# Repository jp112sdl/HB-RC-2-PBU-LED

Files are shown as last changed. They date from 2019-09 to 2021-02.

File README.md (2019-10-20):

# HB-RC-2-PBU-LED

**2 fach Wandtaster, ähnlich dem [HmIP-BSL](https://www.elv.de/elv-homematic-ip-schaltaktor-fuer-markenschalter-mit-signalleuchte-hmip-bsl.html), mit RGB LED Beleuchtung (oben/unten)).**

Thread im Homematic Forum: https://homematic-forum.de/forum/viewtopic.php?f=76&t=53254

### Bauteile
| Anzahl | Ref | Typ | Bezeichnung |
|----|----|----|----|
1 | U1 | AVR | [ATMega 328P-AU](https://www.reichelt.de/mcu-atmega-avr-risc-32-kb-20-mhz-tqfp-32-atmega-328p-au-p119684.html)
2 | R1, R2 | Widerstand 330 | [RND 0805 330](https://www.reichelt.de/smd-widerstand-0805-330-ohm-125-mw-1-rnd-0805-1-330-p183184.html)
2 | R3, R4 | Widerstand 10k | [RND 0805 10k](https://www.reichelt.de/smd-widerstand-0805-10-kohm-125-mw-1-rnd-0805-1-10k-p183251.html)
4 | C2, C4, C5, C7 |Kondensator 100n |[X7R-G0805 100N](https://www.reichelt.de/smd-vielschicht-keramikkondensator-100n-10-x7r-g0805-100n-p31879.html)
1 | C1 | ELKO 1µF/50V | [SMD ELKO 1,0/50](https://www.reichelt.de/smd-chip-elko-1-0-f-50volt-smd-elko-1-0-50-p31900.html)
2 | C3, C6 | ELKO 10µF/16V | [SMD ELKO 10/16](https://www.reichelt.de/smd-chip-elko-10-f-16volt-smd-elko-10-16-p31906.html)
1 | U2 | LDO | [TLV1117-33](https://www.reichelt.de/ldo-regler-fest-3-3-v-sot-223-4-tlv-1117-33-cdcy-p188993.html)
1 | D1 | DuoLED 3mm | [RND 135-00023](https://www.reichelt.de/led-3-mm-bedrahtet-rot-gruen-20-mcd-40-rnd-135-00023-p224130.html)
1 | U3 | LevelShifter | [SN74LVC1T45DBVR](https://www.aliexpress.com/item/32963167201.html)
1 | IC1 | 868MHz Funkmodul | [CC1101](https://www.aliexpress.com/item/32924239954.html)
1 | SW1, SW2, SW3 | Taster | [Tastersortiment](https://www.aliexpress.com/item/32811153729.html)
2 | |WS2812B LED Streifen | [NeoPixel-Stick-WS2812](https://www.amazon.de/NeoPixel-Stick-WS2812-5050-LEDs/dp/B019ZKN3XQ)

### PCB

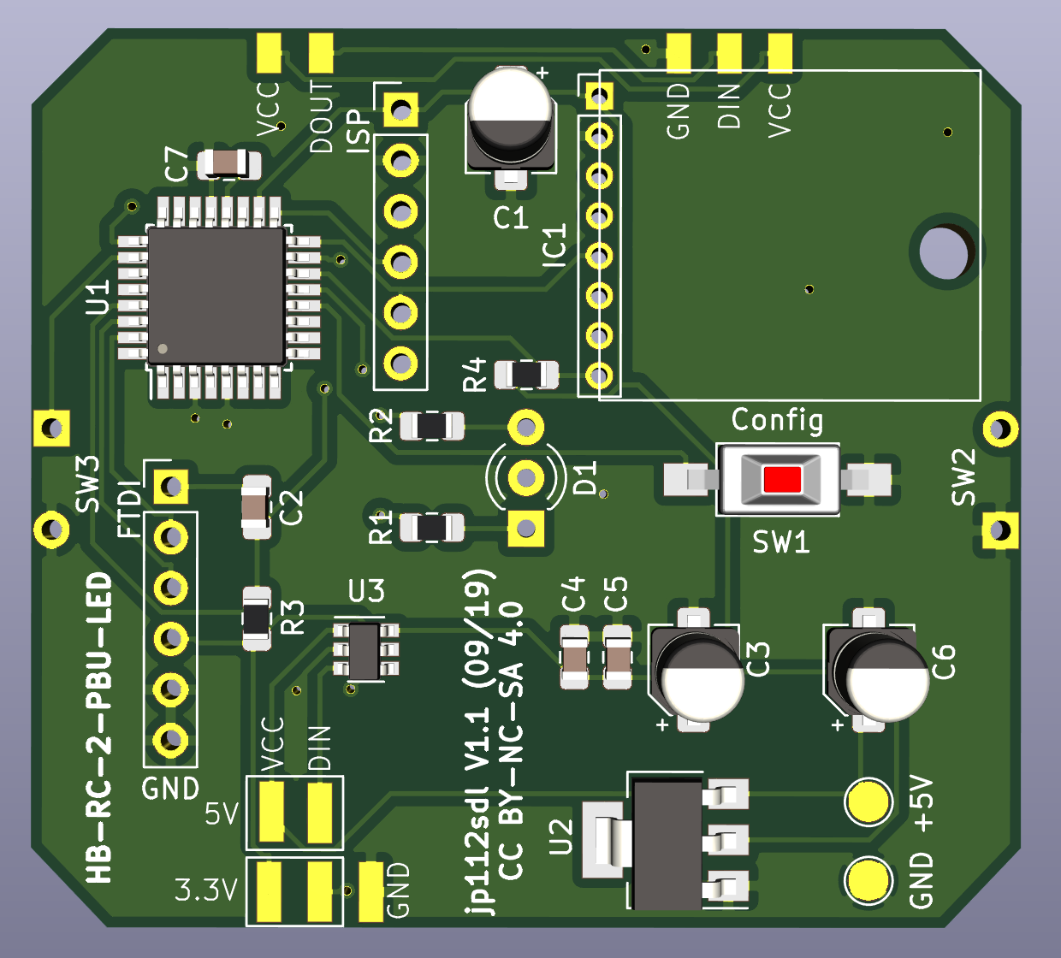
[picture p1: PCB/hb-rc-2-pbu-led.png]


### ein paar Bilder

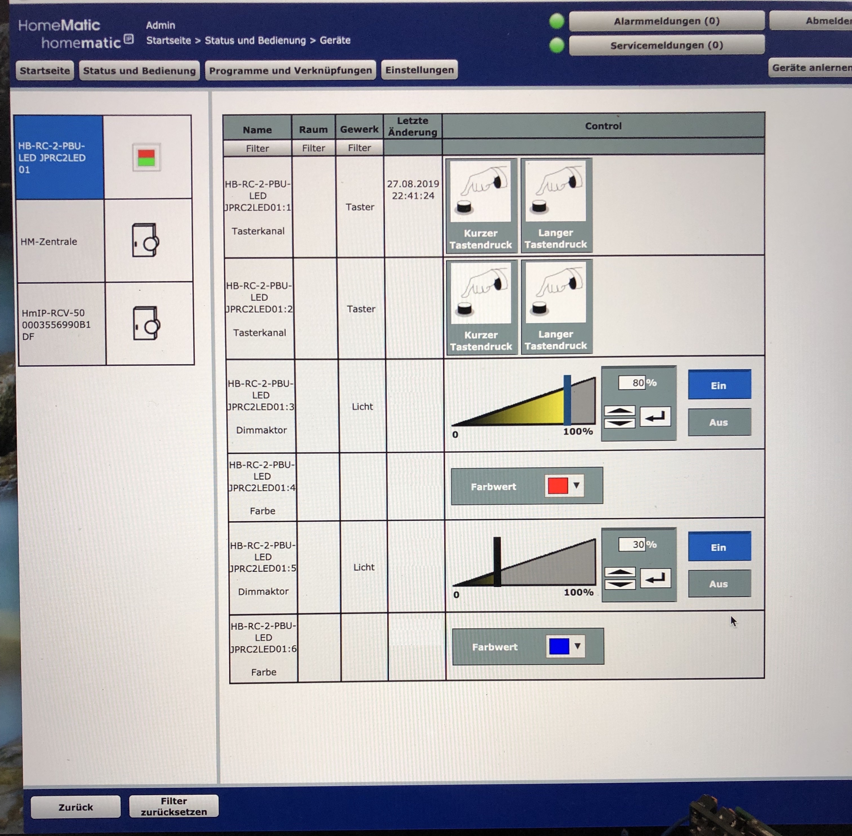
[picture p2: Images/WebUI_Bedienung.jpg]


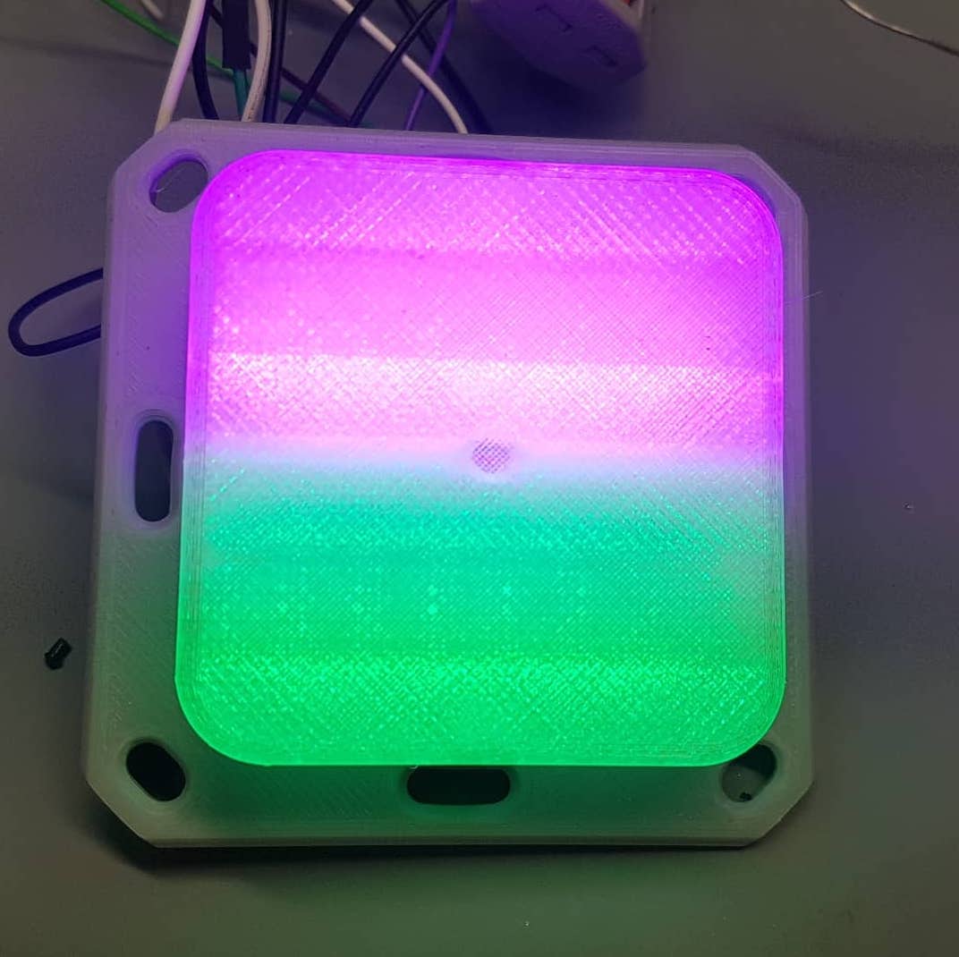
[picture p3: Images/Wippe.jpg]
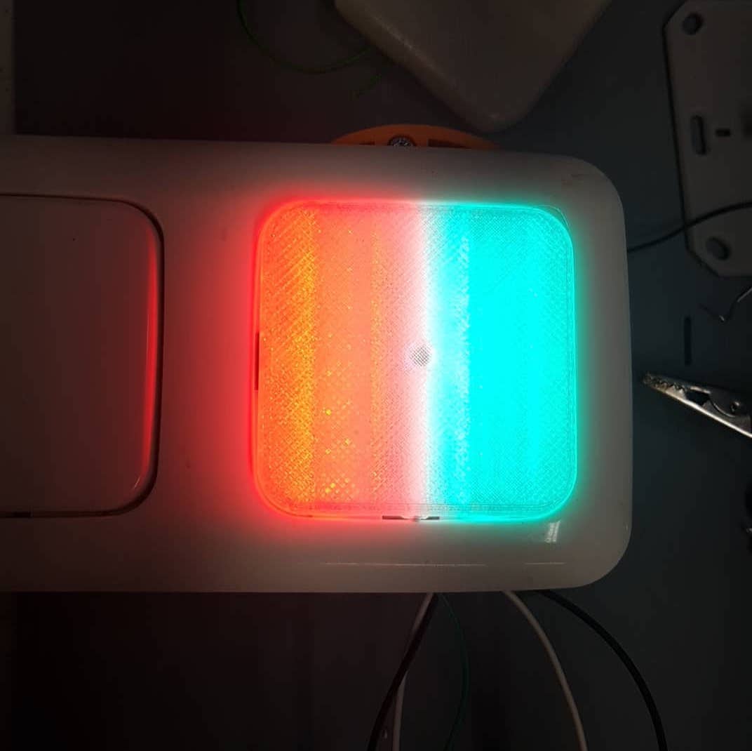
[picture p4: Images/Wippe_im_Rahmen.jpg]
 

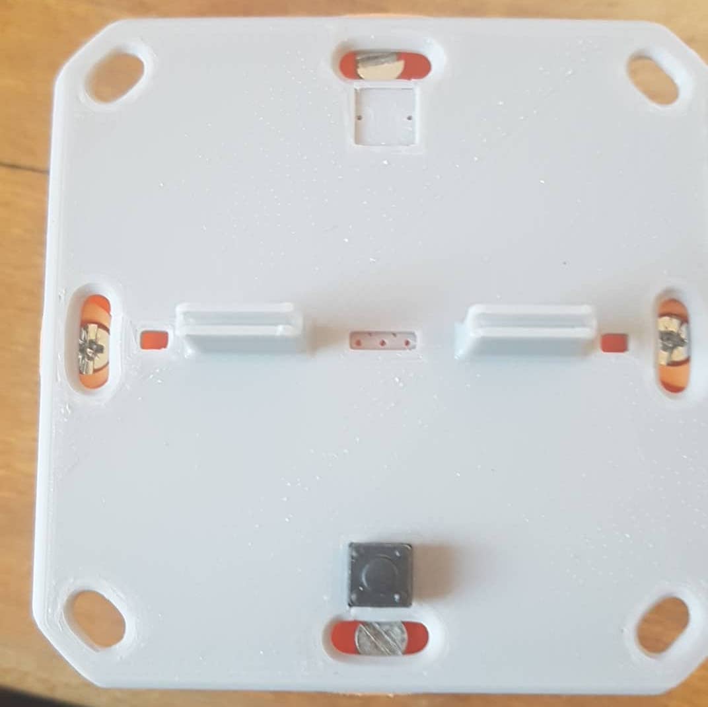
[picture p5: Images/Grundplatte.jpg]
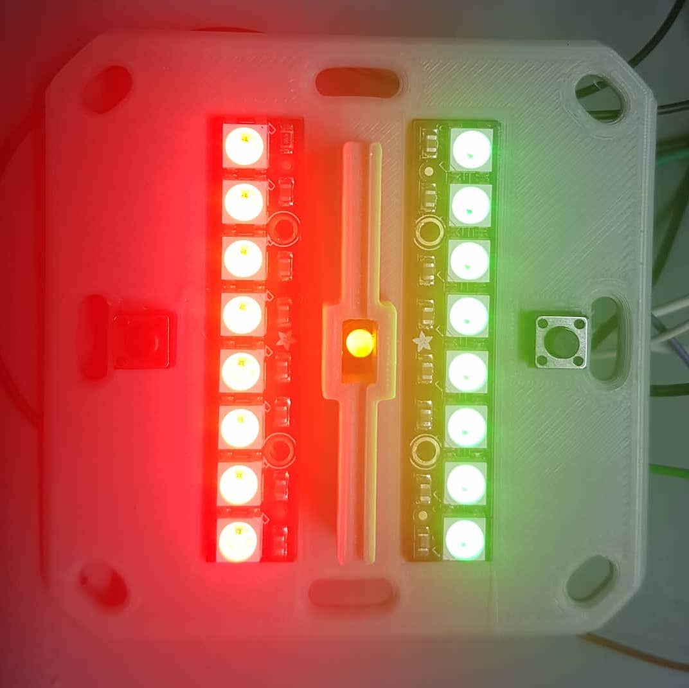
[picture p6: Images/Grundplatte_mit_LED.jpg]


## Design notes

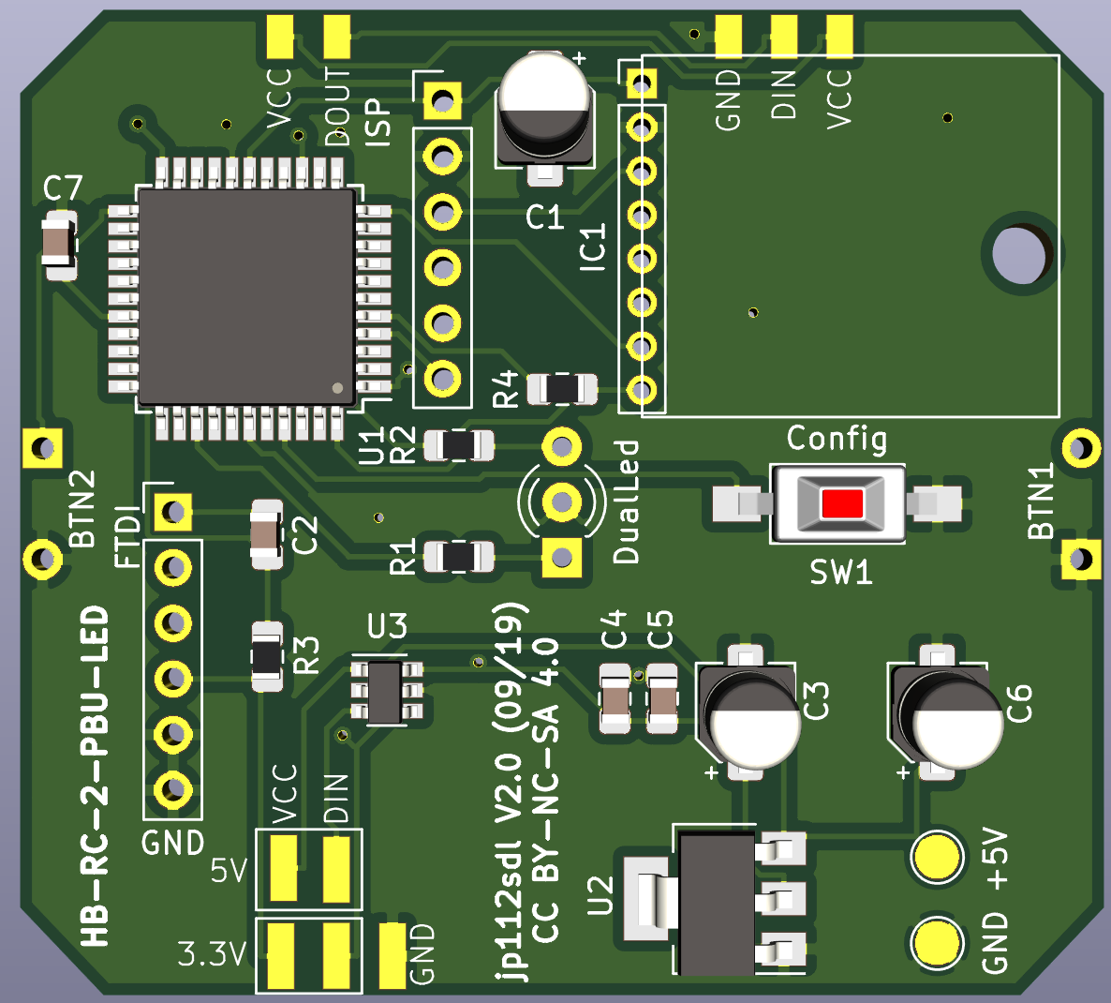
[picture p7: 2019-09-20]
PCB644/hb-rc-2-pbu-led.png

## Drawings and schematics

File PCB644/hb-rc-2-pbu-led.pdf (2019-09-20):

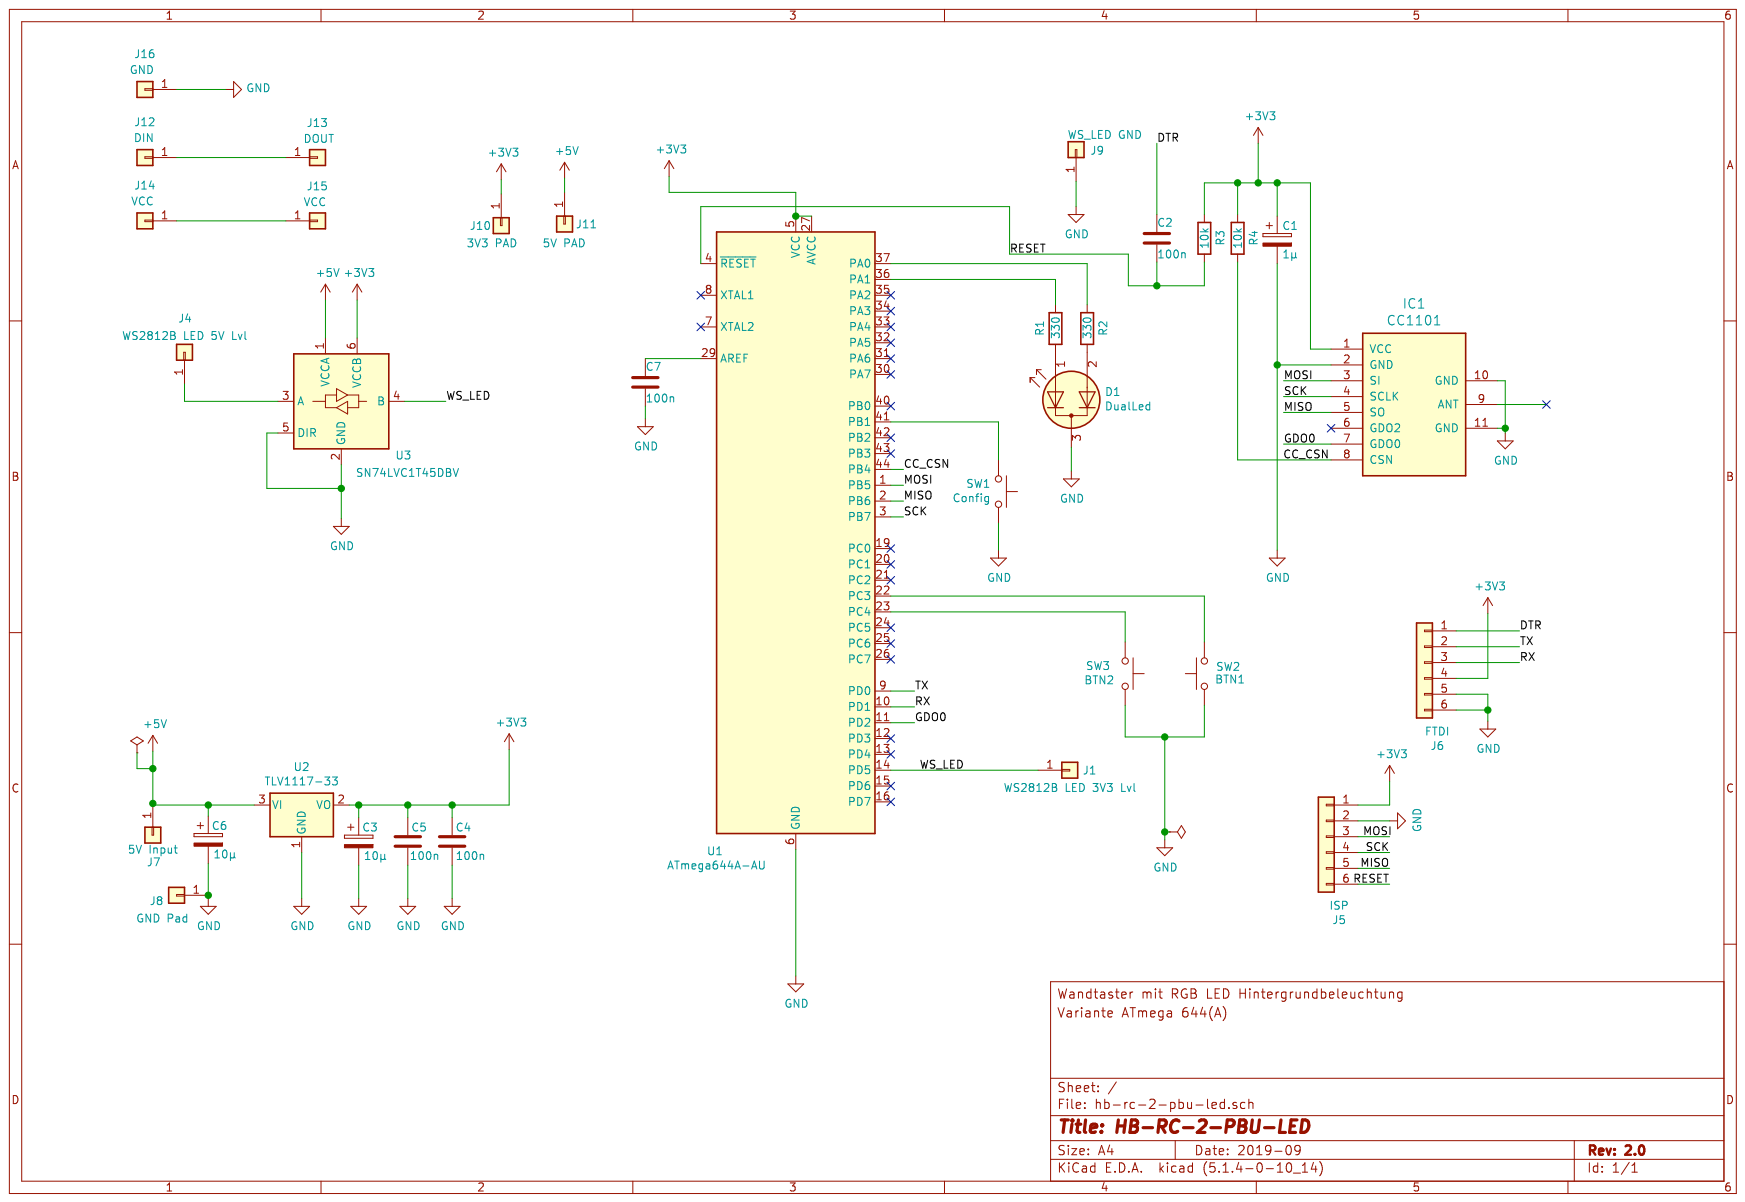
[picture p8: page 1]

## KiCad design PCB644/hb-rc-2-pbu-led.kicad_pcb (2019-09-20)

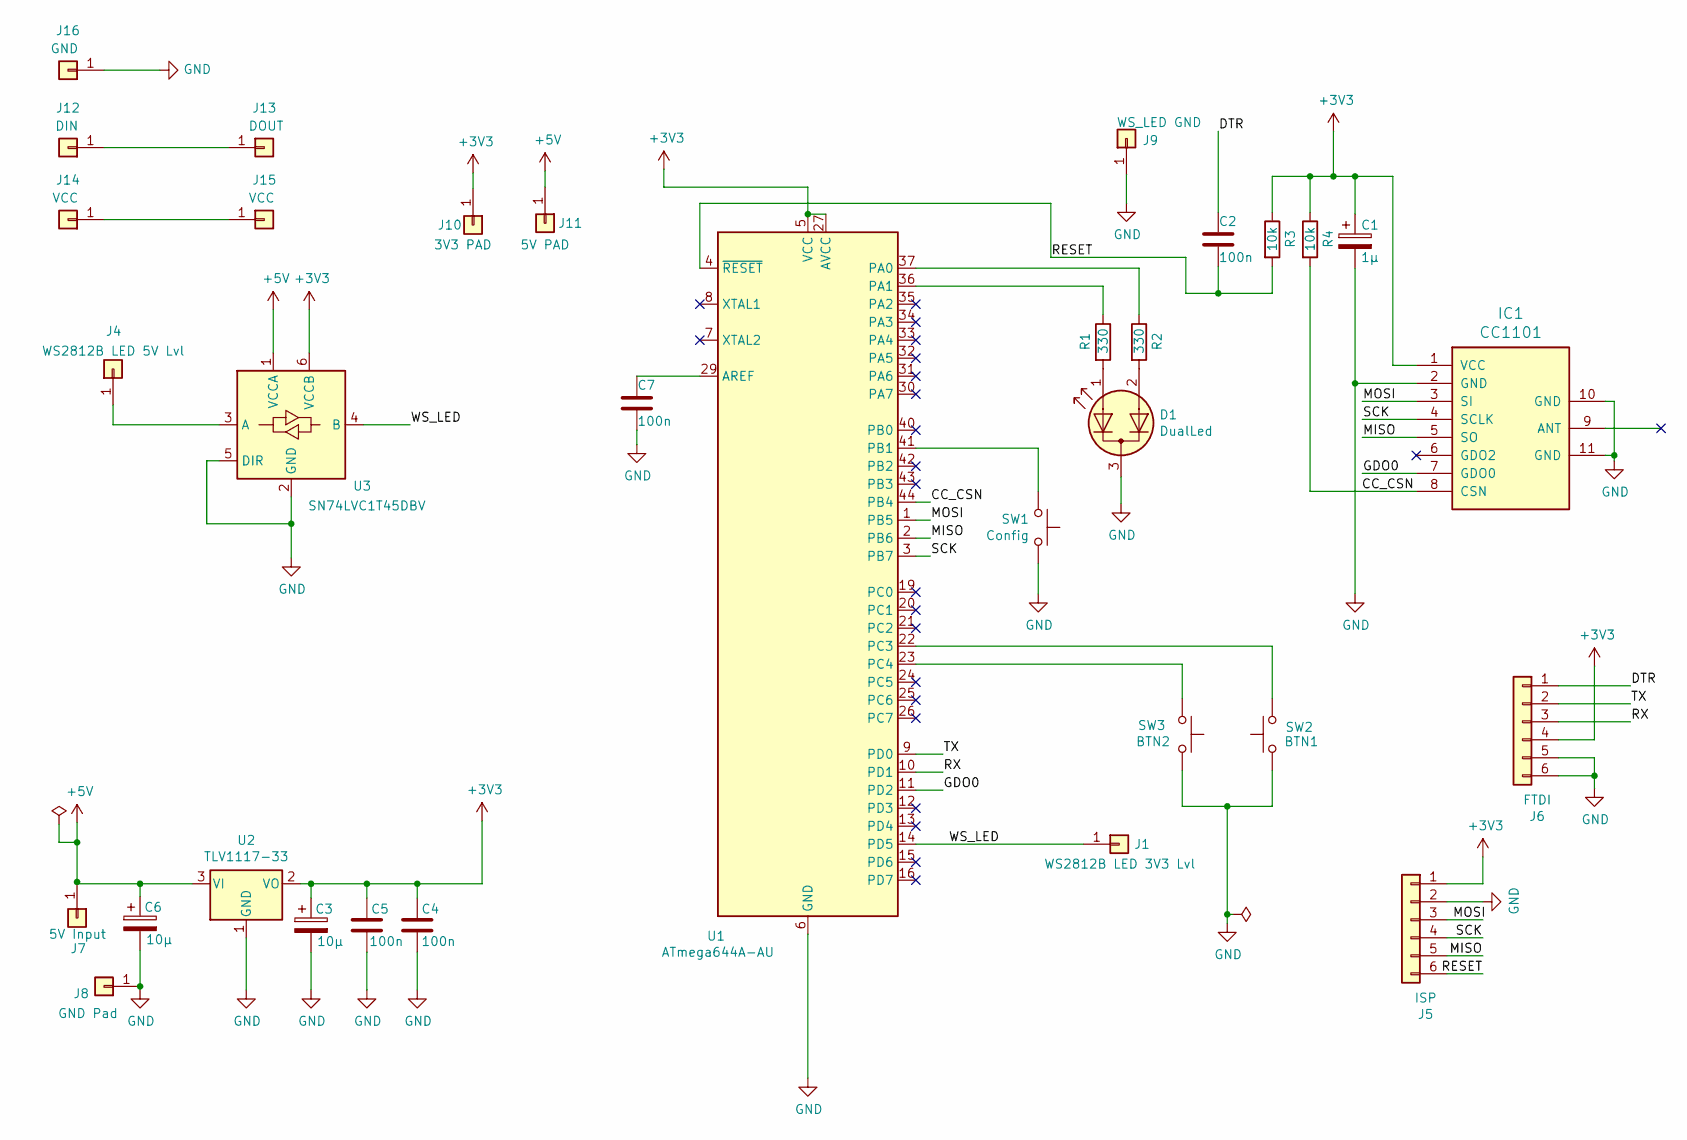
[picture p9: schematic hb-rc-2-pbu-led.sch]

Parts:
C1: 1µ; CP_Elec_4x5.3
C2, C4, C5, C7: 100n; C_0805_2012Metric_Pad1.15x1.40mm_HandSolder
C3, C6: 10µ; CP_Elec_4x5.4
D1: DualLed; LED_D3.0mm-3
IC1: CC1101; PinHeader_1x08_P2.00mm_Vertical
J1: WS2812B LED 3V3 Lvl; TestPoint_Pad_D2.0mm
J4: WS2812B LED 5V Lvl; TestPoint_Pad_D2.0mm
J5: ISP; PinHeader_1x06_P2.54mm_Vertical
J6: FTDI; PinHeader_1x06_P2.54mm_Vertical
J7: 5V Input; TestPoint_Pad_D2.0mm
J8: GND Pad; TestPoint_Pad_D2.0mm
J9: WS_LED GND; TestPoint_Pad_D2.0mm
J10: 3V3 PAD; TestPoint_Pad_D2.0mm
J11: 5V PAD; TestPoint_Pad_D2.0mm
J12: DIN; TestPoint_Pad_D2.0mm
J13: DOUT; TestPoint_Pad_D2.0mm
J14, J15: VCC; TestPoint_Pad_D2.0mm
J16: GND; TestPoint_Pad_D2.0mm
R1, R2: 330; R_0805_2012Metric_Pad1.15x1.40mm_HandSolder
R3, R4: 10k; R_0805_2012Metric_Pad1.15x1.40mm_HandSolder
SW1: Config; SW_SPST_FSMSM
SW2: BTN1; TO-126-2_Vertical
SW3: BTN2; TO-126-2_Vertical
U1: ATmega644A-AU; TQFP-44_10x10mm_P0.8mm
U2: TLV1117-33; SOT-223
U3: SN74LVC1T45DBV; SOT-23-6

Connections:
+3V3: C1.1, C3.1, C4.1, C5.1, IC1.1 (VCC), J5.1, J6.4, J10.1, R3.1, R4.1, U1.5 (VCC), U1.17 (VCC), U1.27 (AVCC), U1.38 (VCC), U2.2 (VO), U3.6 (VCCB)
+5V: C6.1, J7.1, J11.1, U2.3 (VI), U3.1 (VCCA)
/CC_CSN: IC1.8 (CSN), R4.2, U1.44 (PB4)
/DTR: C2.1, J6.1
/GDO0: IC1.7 (GDO0), U1.11 (PD2)
/MISO: IC1.5 (SO), J5.5, U1.2 (PB6)
/MOSI: IC1.3 (SI), J5.3, U1.1 (PB5)
/RESET: C2.2, J5.6, R3.2, U1.4 (~RESET)
/RX: J6.3, U1.10 (PD1)
/SCK: IC1.4 (SCLK), J5.4, U1.3 (PB7)
/TX: J6.2, U1.9 (PD0)
/WS_LED: J1.1, U1.14 (PD5), U3.4 (B)
GND: C1.2, C3.2, C4.2, C5.2, C6.2, C7.2, D1.3 (K), IC1.2 (GND), IC1.10 (GND), IC1.11 (GND), J5.2, J6.5, J6.6, J8.1, J9.1, J16.1, SW1.1, SW2.1, SW3.2, U1.6 (GND), U1.18 (GND), U1.28 (GND), U1.39 (GND), U2.1 (GND), U3.2 (GND), U3.5 (DIR)
unnamed: C7.1, U1.29 (AREF)
unnamed: D1.1 (A1), R1.2
unnamed: D1.2 (A2), R2.2
unnamed: J4.1, U3.3 (A)
unnamed: J12.1, J13.1
unnamed: J14.1, J15.1
unnamed: R1.1, U1.36 (PA1)
unnamed: R2.1, U1.37 (PA0)
unnamed: SW1.2, U1.41 (PB1)
unnamed: SW2.2, U1.22 (PC3)
unnamed: SW3.1, U1.23 (PC4)

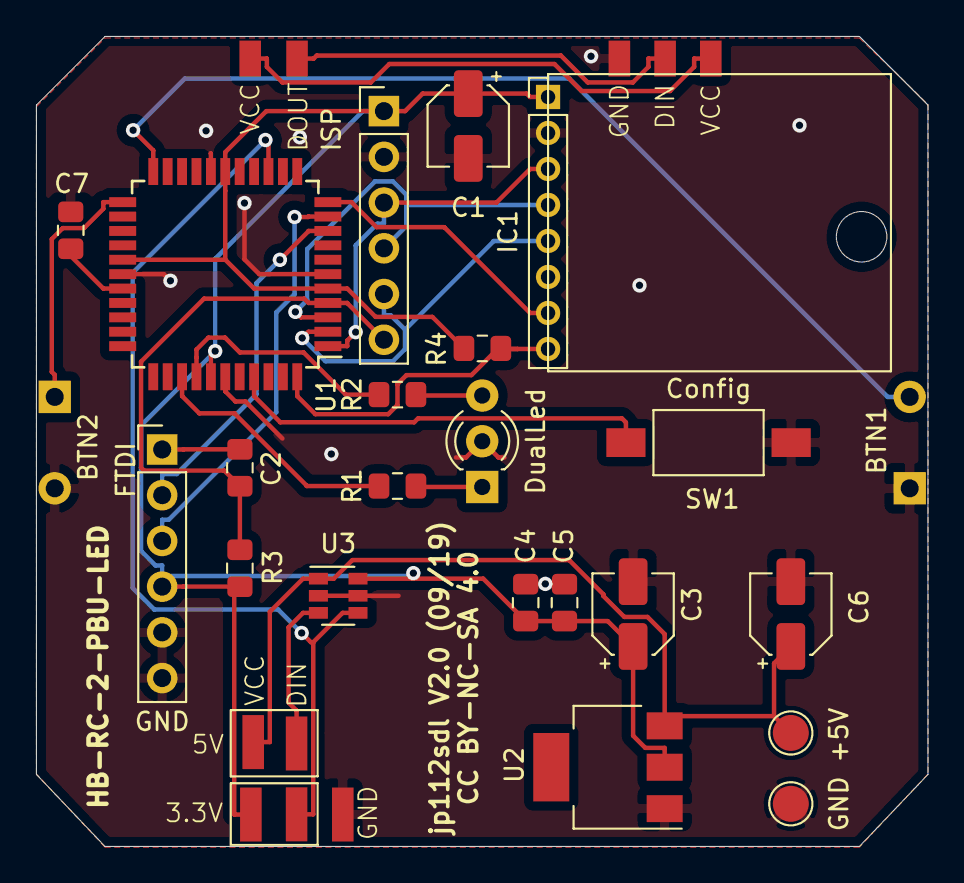
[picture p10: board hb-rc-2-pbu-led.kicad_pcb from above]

Board: 2 copper layers, 49.5 x 45.0 mm, 33 parts (0 on the bottom side), 24 nets.

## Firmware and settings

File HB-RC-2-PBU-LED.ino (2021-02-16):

//- -----------------------------------------------------------------------------------------------------------------------
// AskSin++
// 2019-08-26 jp112sdl Creative Commons - http://creativecommons.org/licenses/by-nc-sa/3.0/de/
//- -----------------------------------------------------------------------------------------------------------------------
// ci-test=yes board=328p aes=no

// define this to read the device id, serial and device type from bootloader section
// #define USE_OTA_BOOTLOADER

#define EI_NOTEXTERNAL
#include <EnableInterrupt.h>
#include <SPI.h>
#include <AskSinPP.h>
#include <LowPower.h>
#include <Register.h>
#include <MultiChannelDevice.h>
#include <FastLED.h>
#include <Remote.h>
#include <Dimmer.h>

//Pin Definitionen (when using 644P(A): use Standard Pinout)

#ifdef __AVR_ATmega328P__
#define CONFIG_BUTTON_PIN 8
#define WSLED_PIN         9      //GPIO Pin LED Anschluss
#define ONBOARD_LED_PIN1  14
#define ONBOARD_LED_PIN2  15
#define CC1101_CS         10
#define CC1101_GDO0       2
#define BTN1_PIN          16
#define BTN2_PIN          17
#endif

#ifdef __AVR_ATmega644P__
#define CONFIG_BUTTON_PIN 1       //PB1
#define WSLED_PIN         13      //PD5 GPIO Pin LED Anschluss
#define ONBOARD_LED_PIN1  25      //PA1
#define ONBOARD_LED_PIN2  24      //PA0
#define CC1101_CS         4       //PB4
#define CC1101_GDO0       10      //PD2
#define BTN1_PIN          19      //PC3
#define BTN2_PIN          20      //PC4
#endif


//Einstellungen für die RGB LEDs
#define WSNUM_LEDS    16          //Anzahl angeschlossener LEDs
#define WSLED_TYPE    WS2812B    //LED Typ
#define WSCOLOR_ORDER GRB        //Farbreihenfolge

uint8_t dim1level(0);
uint8_t dim2level(0);
uint8_t col1val(0);
uint8_t col2val(0);
CRGB leds[WSNUM_LEDS];


#define PEERS_PER_RGB_CHANNEL  3
#define PEERS_PER_RC_CHANNEL   12

using namespace as;

const struct DeviceInfo PROGMEM devinfo = {
  {0xF3, 0x30, 0x00},     // Device ID
  "JPRC2LED01",           // Device Serial
  {0xF3, 0x30},           // Device Model
  0x10,                   // Firmware Version
  as::DeviceType::Dimmer, // Device Type
  {0x01, 0x00}            // Info Bytes
};

typedef AskSin<DualStatusLed<ONBOARD_LED_PIN1, ONBOARD_LED_PIN2>, NoBattery, Radio<LibSPI<CC1101_CS>, CC1101_GDO0>> Hal;
Hal hal;

typedef RemoteChannel<Hal, PEERS_PER_RC_CHANNEL, DimmerList0> RemoteChannelType;
typedef DimmerChannel<Hal, PEERS_PER_RGB_CHANNEL,DimmerList0> RGBLEDChannelType;
typedef DimmerAndRemoteDevice<Hal, RGBLEDChannelType, RemoteChannelType, 4, 1, 2, DimmerList0> RCLEDDevice;

// we need no PWM class
class DummyPWM {
public:
  void init(uint8_t __attribute__ ((unused)) pwm) {}
  void set(uint8_t __attribute__ ((unused)) pwm) {}
  void param(uint8_t __attribute__ ((unused)) speedMultiplier, uint8_t __attribute__ ((unused)) characteristic) {}
};

template<class HalType,class DimmerType,class PWM>
class RGBControl : public DimmerControl<HalType,DimmerType,PWM> {
public:
  typedef DimmerControl<HalType,DimmerType,PWM> BaseControl;
  RGBControl (DimmerType& dim) : BaseControl(dim) {
    for (int i = 0; i < WSNUM_LEDS; i++) {
      leds[i] = CRGB::Black;
    }
    FastLED.addLeds<WSLED_TYPE, WSLED_PIN, WSCOLOR_ORDER>(leds, WSNUM_LEDS);
    FastLED.setBrightness(255);
  }

  virtual ~RGBControl () {}

  virtual void updatePhysical () {
    // first calculate all physical values of the dimmer channels
    BaseControl::updatePhysical();
    // set brightness and color to LEDs
    uint8_t ledprocombi = WSNUM_LEDS / (this->physicalCount() / 2);
    uint8_t ledidx = 0;
    for( uint8_t i=0; i<this->physicalCount();  ) {
      uint8_t dimlevel = this->physical[i++];
      uint8_t collevel = this->physical[i++];
      CRGB ledvalue = CHSV((collevel * 1275L) / 1000, (collevel <  200) ? 255 : 0, dimlevel);
      // set to real LEDs
      for( uint8_t y=0; y<ledprocombi; ++y) {
        leds[ledidx++] = ledvalue;
      }
    }
    FastLED.show();
  }
};

RCLEDDevice sdev(devinfo, 0x20);
RGBControl<Hal,RCLEDDevice,DummyPWM> control(sdev);
ConfigButton<RCLEDDevice> cfgBtn(sdev);

void setup () {
  DINIT(57600, ASKSIN_PLUS_PLUS_IDENTIFIER);
  uint8_t pins[4] = {0,0,0,0}; // all 4 PWM pins are 0
  control.init(hal,pins);
  remoteChannelISR(sdev.remoteChannel(1), BTN1_PIN);
  remoteChannelISR(sdev.remoteChannel(2), BTN2_PIN);
  buttonISR(cfgBtn, CONFIG_BUTTON_PIN);
  sdev.initDone();
}

void loop() {
  bool worked = hal.runready();
  bool poll = sdev.pollRadio();
  if ( worked == false && poll == false ) {
    hal.activity.savePower<Idle<true>>(hal);
  }
}

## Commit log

2019-09-01 use 16 ws2812b leds
2019-09-10 add gerber
    [hb-rc-2-pbu-led-B_Cu.gbr, hb-rc-2-pbu-led-B_Mask.gbr, hb-rc-2-pbu-led-B_SilkS.gbr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]
2019-09-10 add pcb
    [hb-rc-2-pbu-led.kicad_pcb, hb-rc-2-pbu-led.sch]
2019-09-10 pcb update
    [hb-rc-2-pbu-led.kicad_pcb, hb-rc-2-pbu-led.sch]
2019-09-12 fixed wrong ws2812b pin order
    [hb-rc-2-pbu-led-B_Cu.gbr, hb-rc-2-pbu-led-B_Mask.gbr, hb-rc-2-pbu-led-B_SilkS.gbr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]
2019-09-18 fixed missing GND connections
    [hb-rc-2-pbu-led-B_Cu.gbr, hb-rc-2-pbu-led-B_Mask.gbr, hb-rc-2-pbu-led-B_SilkS.gbr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]
2019-09-20 fex missing GND connections
    [hb-rc-2-pbu-led-B_Cu.gbr, hb-rc-2-pbu-led-B_Mask.gbr, hb-rc-2-pbu-led-B_SilkS.gbr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]
2019-09-20 add pcb for atmega644
    [hb-rc-2-pbu-led-B_Cu.gbr, hb-rc-2-pbu-led-B_Mask.gbr, hb-rc-2-pbu-led-B_SilkS.gbr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]
2019-09-20 update pcb files
    [hb-rc-2-pbu-led.sch]
2019-09-26 new pcb image
2020-07-26 add pin definitions for ATmega 644P(A)

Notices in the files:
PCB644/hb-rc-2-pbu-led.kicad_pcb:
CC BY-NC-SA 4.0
